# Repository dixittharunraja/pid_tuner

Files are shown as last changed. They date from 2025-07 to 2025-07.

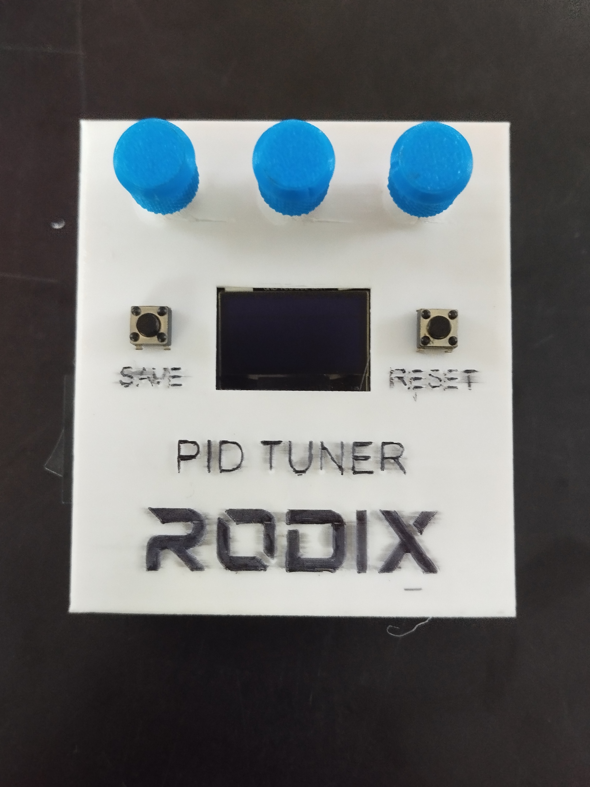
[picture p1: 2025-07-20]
pidtx/media/pidtx3.jpg

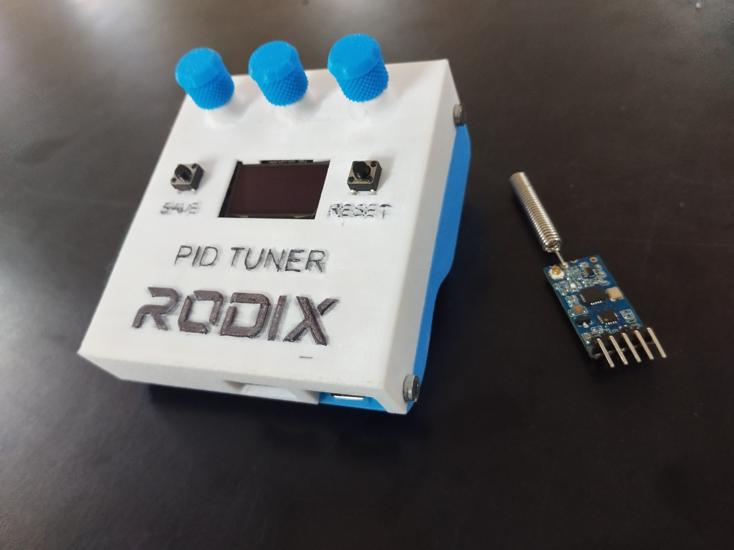
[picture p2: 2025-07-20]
pidtx/media/pid_tuener_tx&rx.jpg

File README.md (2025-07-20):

# pid_tuner

**pid_tuner** by **RODIX (Dixit Tharun Raja P)**



**pid_tuner** is an open-source hardware plus firmware system for convenient, wireless, real-time tuning of PID (Proportional–Integral–Derivative) controller parameters. This project combines a custom-built transmitter (portable, battery powered, encoder-driven) with a simple Arduino-based PID receiver library for direct integration into your robotics, automation, or control system projects.

## 🚀 Features

- **Wireless PID Value Tuning** – Send Kp, Ki, Kd updates via HC-12 radio module—no USB or cable required
- **User-Friendly Physical UI** – 3 rotary encoders with push, crystal-clear OLED display, and two tactile buttons for Save and Reset
- **Live Visual Feedback** – OLED shows each parameter, explicit feedback for ‘Sent’, ‘Save!’, and ‘Reset!’ actions
- **EEPROM Persistence** – Save or reset parameters with a button, persistence across power cycles
- **3D-Printable Enclosure** – Rugged, portable, open hardware design (Fusion 360, .step, .obj included)
- **Simple Integration** – Arduino library for receiver, easy drop-in to your existing project

## 📦 Hardware

| Component | Purpose |
|---|---|
| Arduino Nano | Main controller |
| 3x Rotary Encoders | For Kp/Ki/Kd adjustment |
| 0.96" I2C OLED | Screen feedback |
| 2x Push Buttons | Save & Reset |
| HC-12 Module | Wireless link |
| 360mAh 2S LiPo | Power source |
| MRB045 Charger | Safe, USB-C battery charging |
| 5V 3A BEC | Converts battery to clean 5V |
| 10A Rocker switch | On/off control |
| 3D-printed enclosure  | All files in `enclosure/` |

## 📂 Repository Structure

| Folder | Content |
|---|---|
| `pidtx/` | Transmitter code (`pidtx.ino`), images |
| `pidrx/` | Receiver Arduino library, usage example |
| `enclosure/` | Fusion 360 models, .step/.obj files for 3D printing |
| `README.md` | This overview |
| `INSTRUCTIONS.md`| Full assembly, wiring, and use guide |
| `LICENSE` | License and use terms |

## 🔧 How It Works

* Rotate an encoder → instantly updates value for Kp, Ki, or Kd.
* Press encoder → current value is wirelessly sent (OLED: ‘Kp Sent!’ etc.).
* Press **Save** → All values are saved to EEPROM, OLED: ‘Save!’
* Press **Reset** → All values reset to 0, OLED: ‘Reset!’
* All actions get clear, single-screen, time-limited feedback before returning to the value dashboard.

## 🛠 Quick Start

1. **Assemble** transmitter using instructions and enclosure models.
2. **Program** the transmitter Arduino Nano using `pidtx/pidtx.ino`.
3. **Connect and program** your receiver system using the `pidrx` library (see example).
4. **Tune wirelessly**—no computer needed in the field!

## 🖧 Example Protocol

| Action | HC-12 Serial Command Sent |
|---|---|
| Set Kp | `KP,12\n` |
| Set Ki | `KI,7\n` |
| Set Kd | `KD,3\n` |
| Save to EEPROM| `SAVE\n` |
| Reset | `RESET\n` |

## ⬇️ [Build & Use Instructions](INSTRUCTIONS.md)

See ***INSTRUCTIONS.md*** for full wiring diagrams, enclosure assembly, and troubleshooting.

## 📝 License

**This project is licensed under the Creative Commons Attribution-NonCommercial 4.0 International License (CC BY-NC 4.0).**

_You may use, adapt, remix, and share for non-commercial purposes with proper credit.  
Commercial use is not permitted without the express written permission of ROÐIX (Dixit Tharun Raja P).  
See the `LICENSE` file and https://creativecommons.org/licenses/by-nc/4.0/ for details._

---

_Built with Arduino IDE & Fusion 360.  
&copy; 2025 RODIX (Dixit Tharun Raja P)_

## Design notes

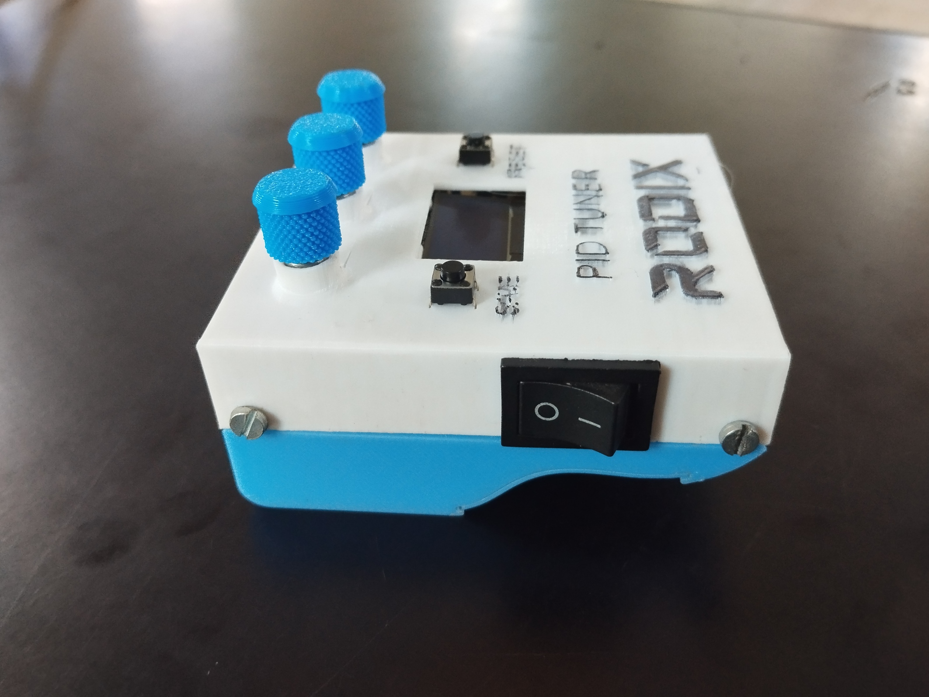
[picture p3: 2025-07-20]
pidtx/media/pidtx1.jpg

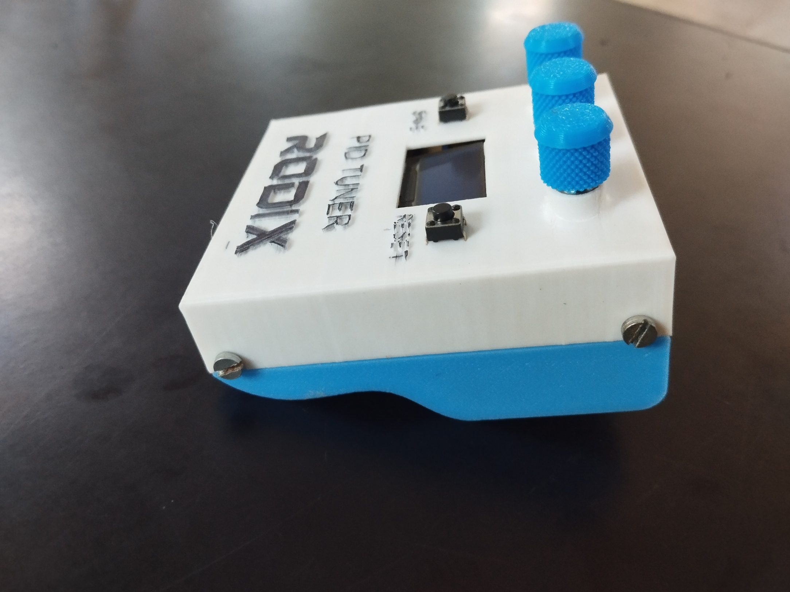
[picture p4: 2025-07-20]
pidtx/media/pidtx2.jpg

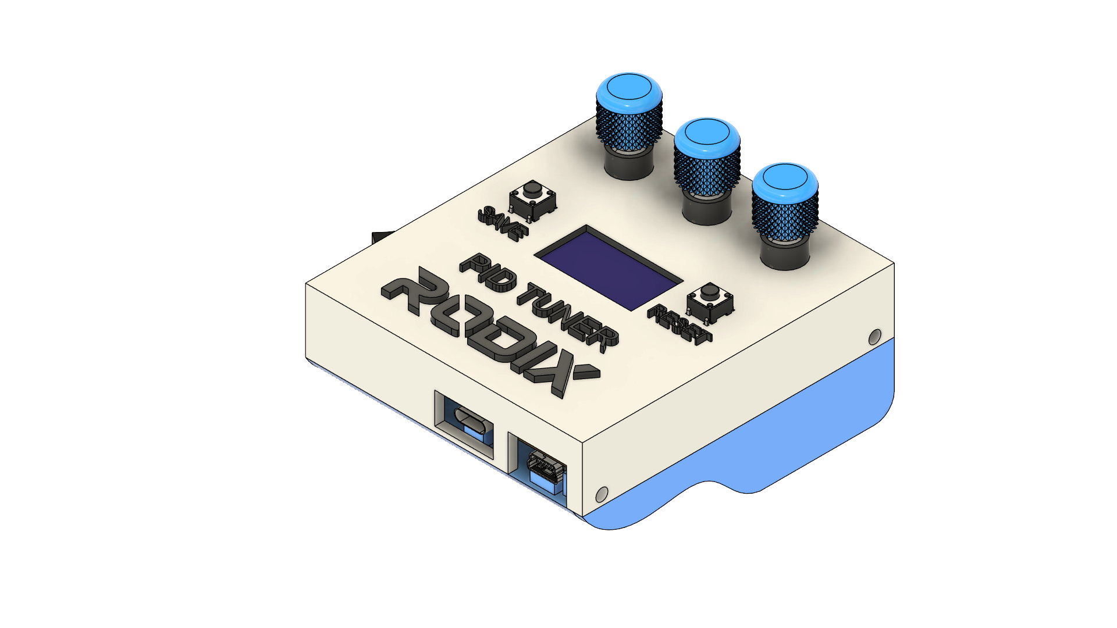
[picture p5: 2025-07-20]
pidtx/media/pid_tuner.png

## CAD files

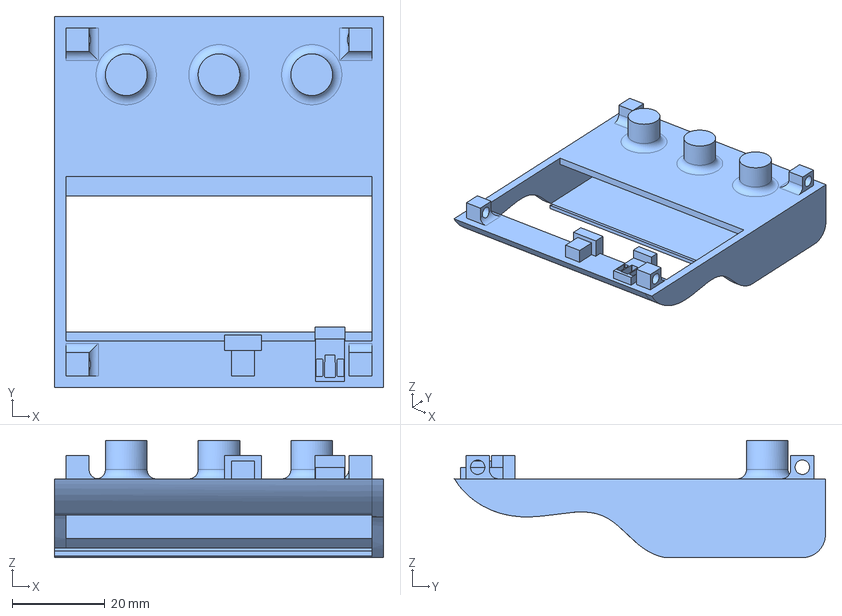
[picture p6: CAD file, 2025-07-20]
pidtx/enclosure/case/Bottom.step
71.0 x 80.0 x 25.3 mm

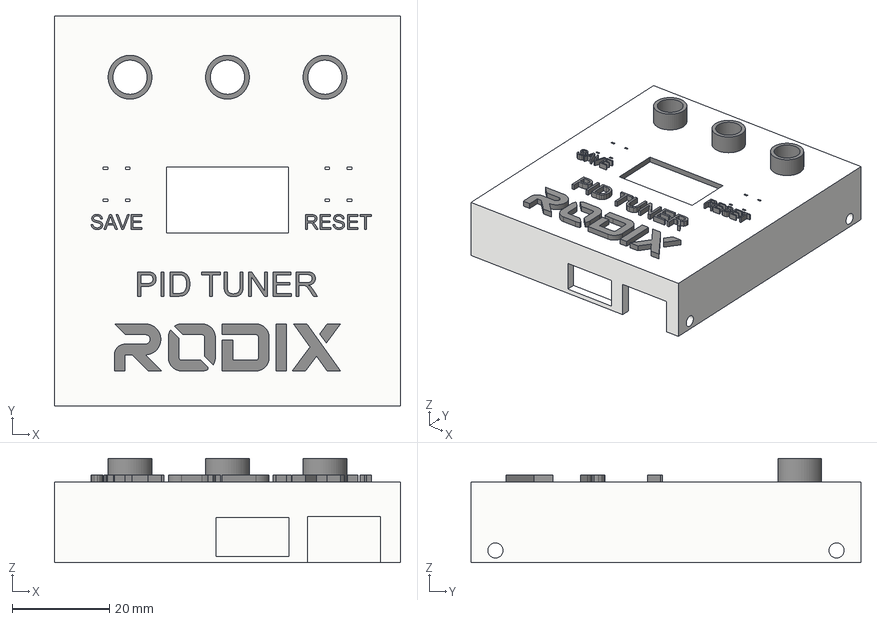
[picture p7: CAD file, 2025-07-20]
pidtx/enclosure/case/Top.step
71.0 x 80.0 x 21.4 mm

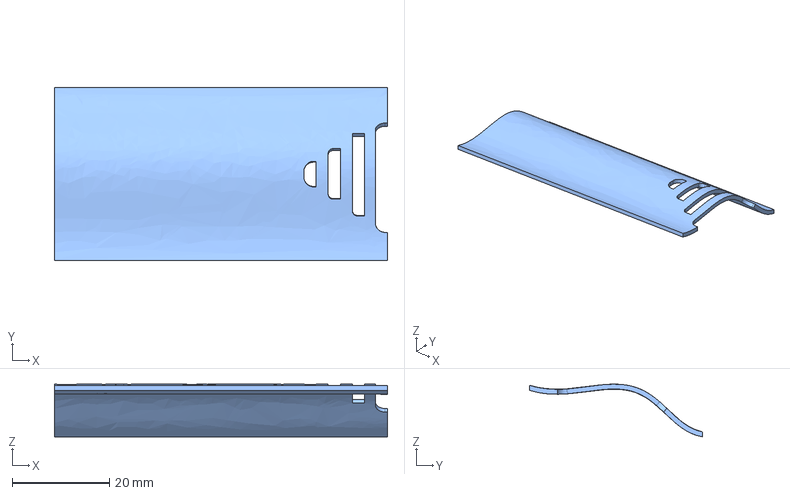
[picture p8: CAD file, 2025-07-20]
pidtx/enclosure/case/Lid.step
68.5 x 35.5 x 10.8 mm

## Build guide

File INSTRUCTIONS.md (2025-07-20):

# PID Tuner – Detailed Build, Wiring & Use Guide

_by RODIX (Dixit Tharun Raja P)_

This guide will help you assemble, wire, program, and operate your PID tuner hardware for the smoothest out-of-the-box experience.

---

## 1. Required Components

| Qty | Item |
|-----|---|
| 1 | Arduino Nano |
| 3 | Rotary encoders (with push button) |
| 1 | 0.96" I2C OLED display |
| 2 | Mini push buttons |
| 1 | HC-12 wireless module |
| 1 | 360mAh 2S LiPo battery |
| 1 | MRB045 2S LiPo USB-C charger module |
| 1 | BEC 5V 3A voltage regulator |
| 1 | Rocker switch (10A) |
| — | 3D-printed enclosure (see `enclosure/`) |

---

## 2. Wiring Diagram

**Power System:**

[2S LiPo]──[MRB045 Charger]
|
+──[BEC 5V 3A]──[Rocker Switch]──[Arduino VIN]

- All peripherals (OLED, encoders, HC-12, buttons) wired to Nano (5V & GND).
- NEVER charge and run the device at the same time! Disconnect load before charging.

**Typical Peripheral Connection Table**

| Part | Arduino Pins | Notes |
|---|---|---|
| Kp encoder | D10 (CLK), D11 (DT), D12 (SW) | |
| Ki encoder | D7  (CLK), D8  (DT), D9  (SW) | |
| Kd encoder | D4  (CLK), D5  (DT), D6  (SW) | |
| OLED | SDA (A4), SCL (A5)| 5V, GND |
| Save button | A2 | Active LOW, to GND |
| Reset button | A3 | Active LOW, to GND |
| HC-12 | D3 (RX), D2 (TX)  | 5V, GND |

**Tip:** Adjust your connections if you need, just update the sketch pin numbers as well.

---

## 3. Enclosure Assembly

- Print parts in `enclosure/`: `case/bottom`, `case/lid`, `case/top`, and `knob.step`.
- Install Nano, OLED, encoders, buttons, HC-12, and battery into the case.
- Secure rocker switch, close lid.
- Recommended: PLA, 0.2mm layer height, 15% infill.

---

## 4. Firmware Upload

- Open `pidtx/pidtx.ino` in Arduino IDE.
- Select Arduino Nano, correct COM port.
- Upload code. Connect HC-12 after flashing to avoid serial conflicts.

---

## 5. Charging & Safety

- To **charge**: Disconnect BEC from battery and plug USB-C into MRB045 charger; connect battery (BAT+/-) to the module.
- Never charge and operate at the same time!
- Always supervise LiPo charging and use a safe charging bag.

---

## 6. Operation

1. Flip rocker switch ON.
2. OLED displays Kp, Ki, Kd.  
3. Rotate encoders to change values (per step!).  
4. Press encoder to send (`Kp Sent!`, etc. appears briefly onscreen).  
5. Press SAVE (A2) to store values in EEPROM: `Save!` displays for 1s.  
6. Press RESET (A3) to zero all values: `Reset!` displays for 1s.  
7. All actions appear and auto-return to value dashboard. Wireless commands sent over HC-12 immediately.

---

## 7. Troubleshooting

- **OLED blank:** Check wiring, I2C address (should be 0x3C), verify voltage.
- **Encoder glitch:** Recheck GND; debounce logic is handled in code.
- **"Sent!"/others not displaying:** Confirm logic and action in code (see `showPID()`).
- **Wireless fails:** Confirm HC-12 baud (9600), antenna connected, wiring correct.

---

## 8. Customization

- Edit encoder pin config in code for your preferences.
- Adjust `sentDisplayDuration` (ms) for feedback time.
- You can modify enclosure in Fusion 360 or remix with .step/.obj.

---

## 9. Receiver Integration

See `pidrx/examples/BasicUsage/BasicUsage.ino` and library documentation for adding to your robot or industrial controller.

---

_Questions, suggestions, or remixes? Open an issue or PR!_

&copy; 2025 RODIX (Dixit Tharun Raja P)

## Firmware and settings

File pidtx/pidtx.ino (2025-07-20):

#include <Wire.h>
#include <Adafruit_GFX.h>
#include <Adafruit_SSD1306.h>
#include <digitalWriteFast.h>
#include <EEPROM.h>
#include <SoftwareSerial.h>

SoftwareSerial hc12(3, 2);

#define SCREEN_WIDTH 128
#define SCREEN_HEIGHT 64
#define OLED_RESET    -1
#define OLED_ADDR     0x3C

Adafruit_SSD1306 display(SCREEN_WIDTH, SCREEN_HEIGHT, &Wire, OLED_RESET);

const unsigned long sentDisplayDuration = 1000;

struct Encoder {
  const int clkPin, dtPin, swPin;
  volatile int value;
  int lastCLK;
  bool sendFlag;
  bool sent;
  unsigned long sentTime;
  const char* label;
  int y;
};

const int saveButtonPin = A2;
const int resetButtonPin = A3;

enum DisplayMode { NORMAL, SHOW_SENT, SHOW_SAVE, SHOW_RESET };
DisplayMode displayMode = NORMAL;
unsigned long displayStateTime = 0;
int sentParamIdx = -1; // 0 = kp, 1 = ki, 2 = kd

Encoder encoders[] = {
  {10, 11, 12, 0, 0, HIGH, false, 0, "Kp", 0},
  {7, 8, 9, 0, 0, HIGH, false, 0, "Ki", 22},
  {4, 5, 6, 0, 0, HIGH, false, 0, "Kd", 44}
};
const int NUM_ENCODERS = sizeof(encoders)/sizeof(encoders[0]);

const int EEPROM_ADDR[NUM_ENCODERS] = {0, 4, 8};

void printToOLED(const char* text, int x, int y, int textSize = 2, uint16_t color = SSD1306_WHITE) {
  display.setTextSize(textSize);
  display.setTextColor(color);
  display.setCursor(x, y);
  display.print(text);
}

void setup() {
  Serial.begin(9600);
  hc12.begin(9600);

  if (!display.begin(SSD1306_SWITCHCAPVCC, OLED_ADDR)) {
    for (;;);
  }
  display.clearDisplay();

  for (int i = 0; i < NUM_ENCODERS; ++i) {
    pinMode(encoders[i].clkPin, INPUT);
    pinMode(encoders[i].dtPin, INPUT);
    pinMode(encoders[i].swPin, INPUT_PULLUP);
    encoders[i].lastCLK = digitalReadFast(encoders[i].clkPin);
  }

  pinMode(saveButtonPin, INPUT_PULLUP);
  pinMode(resetButtonPin, INPUT_PULLUP);

  loadPIDValuesFromEEPROM();

  showPID();
}

void loop() {
  bool needUpdate = false;
  for (int i = 0; i < NUM_ENCODERS; ++i) {
    needUpdate |= readEncoder(encoders[i], i);
  }

  unsigned long now = millis();
  for (int i = 0; i < NUM_ENCODERS; ++i) {
    if (encoders[i].sent && now - encoders[i].sentTime > sentDisplayDuration) {
      encoders[i].sent = false;
      needUpdate = true;
    }
  }

  if (displayMode != NORMAL && millis() - displayStateTime > sentDisplayDuration) {
      displayMode = NORMAL;
      sentParamIdx = -1;
      showPID();
  }

  checkButtons();

  if (needUpdate) showPID();
}

bool readEncoder(Encoder &enc, int idx) {
  bool updated = false;
  int currCLK = digitalReadFast(enc.clkPin);

  if (currCLK != enc.lastCLK && currCLK == HIGH) {
    enc.value += (digitalReadFast(enc.dtPin) == LOW) ? 1 : -1;
    updated = true;
  }
  enc.lastCLK = currCLK;

  bool btn = digitalReadFast(enc.swPin);
  if (!btn && enc.sendFlag) {
    enc.sent = true;
    enc.sentTime = millis();
    updated = true;
    sendSinglePID(idx);
    delay(200); // debounce
  }
  enc.sendFlag = btn;

  return updated;
}

void showPID() {
    display.clearDisplay();

    if (displayMode == SHOW_SAVE) {
        printToOLED("Save!", 36, 28, 2);
    } else if (displayMode == SHOW_RESET) {
        printToOLED("Reset!", 30, 28, 2);
    } else if (displayMode == SHOW_SENT) {
        const char* paramName = encoders[sentParamIdx].label;
        char buf[16];
        snprintf(buf, sizeof(buf), "%s Sent!", paramName);
        printToOLED(buf, 30, 28, 2);
    } else { // NORMAL
        char buf[16];
        for (int i = 0; i < NUM_ENCODERS; ++i) {
            snprintf(buf, sizeof(buf), "%s: %d", encoders[i].label, encoders[i].value);
            printToOLED(buf, 0, encoders[i].y, 2);
        }
    }
    display.display();
}


void checkButtons() {
  int readingSave = digitalRead(saveButtonPin);
  if (readingSave == LOW) {
      savePIDValues();
      Serial.print("SAVE\n");
      hc12.print("SAVE\n");
      displayMode = SHOW_SAVE;
      displayStateTime = millis();
  }

  int readingReset = digitalRead(resetButtonPin);
  if (readingReset == LOW) {
      resetPIDValues();
      Serial.print("RESET\n");
      hc12.print("RESET\n");
      displayMode = SHOW_RESET;
      displayStateTime = millis();
  }
}

void loadPIDValuesFromEEPROM() {
  for (int i = 0; i < NUM_ENCODERS; ++i) {
    int val = 0;
    EEPROM.get(EEPROM_ADDR[i], val);
    encoders[i].value = val;
  }
}

void savePIDValues() {
  unsigned long now = millis();
  for (int i = 0; i < NUM_ENCODERS; ++i) {
    EEPROM.put(EEPROM_ADDR[i], encoders[i].value);
    encoders[i].sent = true;
    encoders[i].sentTime = now;
  }
  showPID();
}

void resetPIDValues() {
  for (int i = 0; i < NUM_ENCODERS; ++i) {
    encoders[i].value = 0;
    encoders[i].sent = false;
  }
  showPID();
}

void sendSinglePID(int idx) {
  String msg;
  switch (idx) {
    case 0: // Kp
      msg = "KP," + String(encoders[0].value) + "\n";
      break;
    case 1: // Ki
      msg = "KI," + String(encoders[1].value) + "\n";
      break;
    case 2: // Kd
      msg = "KD," + String(encoders[2].value) + "\n";
      break;
    default:
      return;
  }
  Serial.print(msg);
  hc12.print(msg);
  displayMode = SHOW_SENT;
  sentParamIdx = idx;
  displayStateTime = millis();
}

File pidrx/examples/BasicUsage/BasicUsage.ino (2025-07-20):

#include <pidrx.h>

pidrx pidReceiver(8, 9);  // RX, TX pins connected to HC-12

void setup() {
  Serial.begin(9600);
  pidReceiver.begin();
  Serial.println("pidrx example started");
}

void loop() {
  pidReceiver.update();

  int kp = pidReceiver.getKp();
  int ki = pidReceiver.getKi();
  int kd = pidReceiver.getKd();

  Serial.print("Kp: "); Serial.print(kp);
  Serial.print(" | Ki: "); Serial.print(ki);
  Serial.print(" | Kd: "); Serial.println(kd);

  delay(1000);
}
